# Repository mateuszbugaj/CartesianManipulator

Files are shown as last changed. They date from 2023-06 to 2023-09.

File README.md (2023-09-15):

# CartesianManipulator
This repository contains the firmware for a three-axis manipulator system. The manipulator utilizes three stepper motors controlled by A4988 stepper motor drivers. This project is designed for AVR microcontrollers.

## Overview
The manipulator has three axes: X, Y, and Z, each controlled by a stepper motor. Each axis also has an edge switch to determine its limit. The project code includes routines for handling move commands, speed changes, precision and normal mode, and homing.

Demo of the manipulator: [CartesianManipulatorDemo.gif](CartesianManipulatorDemo.gif) <br/><br/>
df

The project also includes a USART serial communication module and a basic command parser for controlling the manipulator. The manipulator can be controlled in relative or absolute positioning modes.

## Hardware
The hardware requirements for this project include:

1. AVR microcontroller
2. Three A4988 stepper motor drivers
3. Three stepper motors
4. Three edge switches
5. Gripper with servo motor

Files describing PCB layout can be found in `PCB/` directory.

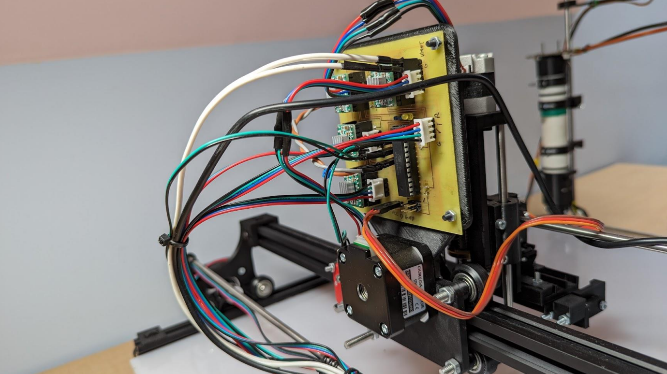
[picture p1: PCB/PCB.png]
df


## Software
The firmware is written in C and requires AVR GCC to compile.

Clone this repository to your local machine.
Open the project in your AVR development environment.
Build the project and flash the compiled firmware onto your AVR microcontroller.

```bash
make && make flash
```

## Usage
You can control the manipulator via USART using the following commands:

1. G0 \<X> \<Y> \<Z> : Move the manipulator to the specified position.
2. G28 : Home the manipulator.
3. F \<S> : Change the speed of the manipulator.
4. PREC : Switch the manipulator to precision mode.
5. NORM : Switch the manipulator to normal mode.
6. M \<G> : Control the gripper openness.
7. ZERO : Zero the manipulator's position.
8. LIMITX \<L> \<U> : Set the lower and upper limits for the X axis.
9. LIMITY \<L> \<U> : Set the lower and upper limits for the Y axis.
10. LIMITZ \<L> \<U> : Set the lower and upper limits for the Z axis.
11. G90 : Switch to relative positioning mode.
12. G91 : Switch to absolute positioning mode.

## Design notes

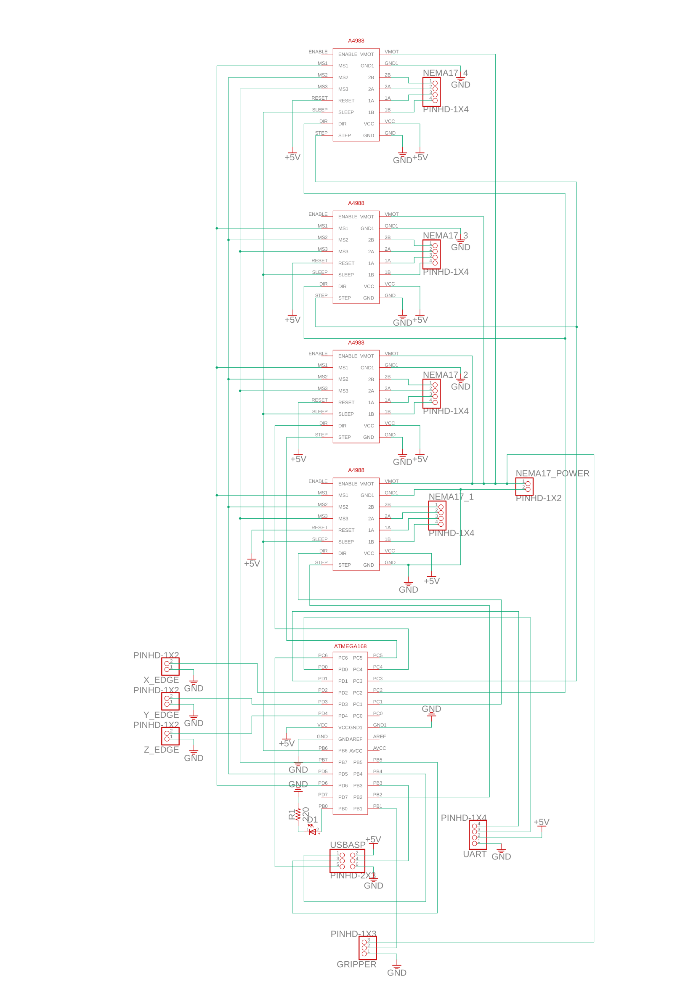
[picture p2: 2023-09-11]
PCB/PCB_Schematics.png

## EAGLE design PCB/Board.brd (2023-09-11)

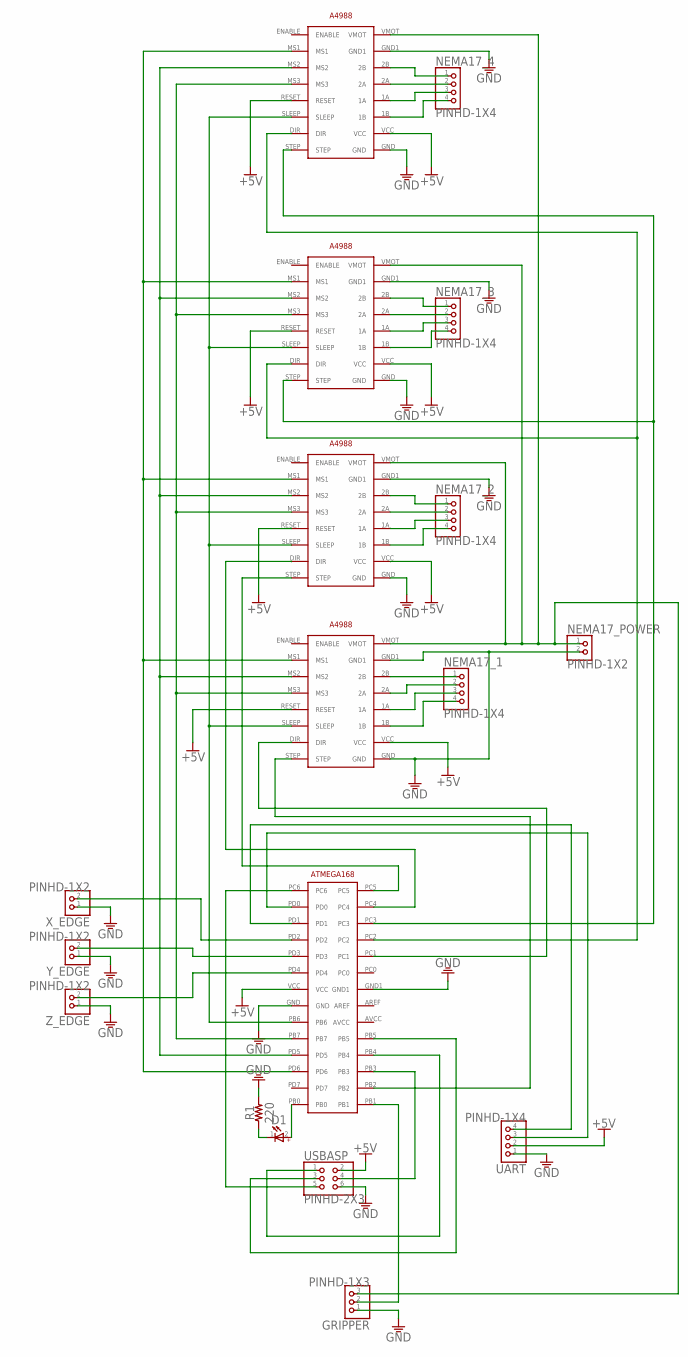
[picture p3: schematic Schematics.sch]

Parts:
D1: 151033BS03000; WL-TMRW_3MM_STOPPER
GRIPPER: PINHD-1X3; 1X03
NEMA17_1, NEMA17_2, NEMA17_3, NEMA17_4: PINHD-1X4; 1X04
NEMA17_POWER: PINHD-1X2; 1X02
R1: 220; RESAD724W46L381D178B
U$1: ATMEGA168; ATMEGA168FOOTPRINT
U$2, U$3, U$4, U$5: A4988; A498-FOOTPRINT
UART: PINHD-1X4; 1X04
USBASP: PINHD-2X3; 2X03
X_EDGE: PINHD-1X2; 1X02
Y_EDGE: PINHD-1X2; 1X02
Z_EDGE: PINHD-1X2; 1X02

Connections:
+5V: U$1.VCC, U$2.RESET, U$2.VCC, U$3.RESET, U$3.VCC, U$4.RESET, U$4.VCC, U$5.RESET, U$5.VCC, UART.2, USBASP.2
GND: GRIPPER.1, NEMA17_POWER.2, R1.2, U$1.GND, U$1.GND1, U$2.GND, U$2.GND1, U$3.GND, U$3.GND1, U$4.GND, U$4.GND1, U$5.GND, U$5.GND1, UART.1, USBASP.6, X_EDGE.1, Y_EDGE.1, Z_EDGE.1
unnamed: U$1.PB3, USBASP.4
unnamed: U$1.PB4, USBASP.1
unnamed: U$1.PB5, USBASP.3
unnamed: U$1.PC6, USBASP.5
unnamed: D1.2 (+), U$1.PB0
unnamed: D1.1 (-), R1.1
unnamed: U$1.PD0, UART.3
unnamed: U$1.PD1, UART.4
unnamed: NEMA17_1.1, U$2.2B
unnamed: NEMA17_1.2, U$2.2A
unnamed: NEMA17_1.3, U$2.1A
unnamed: NEMA17_1.4, U$2.1B
unnamed: U$1.PB2, U$2.STEP
unnamed: GRIPPER.3, NEMA17_POWER.1, U$2.VMOT, U$3.VMOT, U$4.VMOT, U$5.VMOT
unnamed: U$1.PC1, U$2.DIR
unnamed: U$1.PB6, U$2.SLEEP, U$3.SLEEP, U$4.SLEEP, U$5.SLEEP
unnamed: U$1.PB7, U$2.MS3, U$3.MS3, U$4.MS3, U$5.MS3
unnamed: U$1.PD5, U$2.MS2, U$3.MS2, U$4.MS2, U$5.MS2
unnamed: U$1.PD6, U$2.MS1, U$3.MS1, U$4.MS1, U$5.MS1
unnamed: NEMA17_2.4, U$3.1B
unnamed: NEMA17_2.3, U$3.1A
unnamed: NEMA17_2.2, U$3.2A
unnamed: NEMA17_2.1, U$3.2B
unnamed: U$1.PC5, U$3.STEP
unnamed: U$1.PC4, U$3.DIR
unnamed: NEMA17_3.4, U$4.1B
unnamed: NEMA17_3.3, U$4.1A
unnamed: NEMA17_3.2, U$4.2A
unnamed: NEMA17_3.1, U$4.2B
unnamed: U$1.PC3, U$4.STEP, U$5.STEP
unnamed: U$1.PC2, U$4.DIR, U$5.DIR
unnamed: NEMA17_4.4, U$5.1B
unnamed: NEMA17_4.3, U$5.1A
unnamed: NEMA17_4.2, U$5.2A
unnamed: NEMA17_4.1, U$5.2B
unnamed: U$1.PD2, X_EDGE.2
unnamed: U$1.PD3, Y_EDGE.2
unnamed: U$1.PD4, Z_EDGE.2
unnamed: GRIPPER.2, U$1.PB1

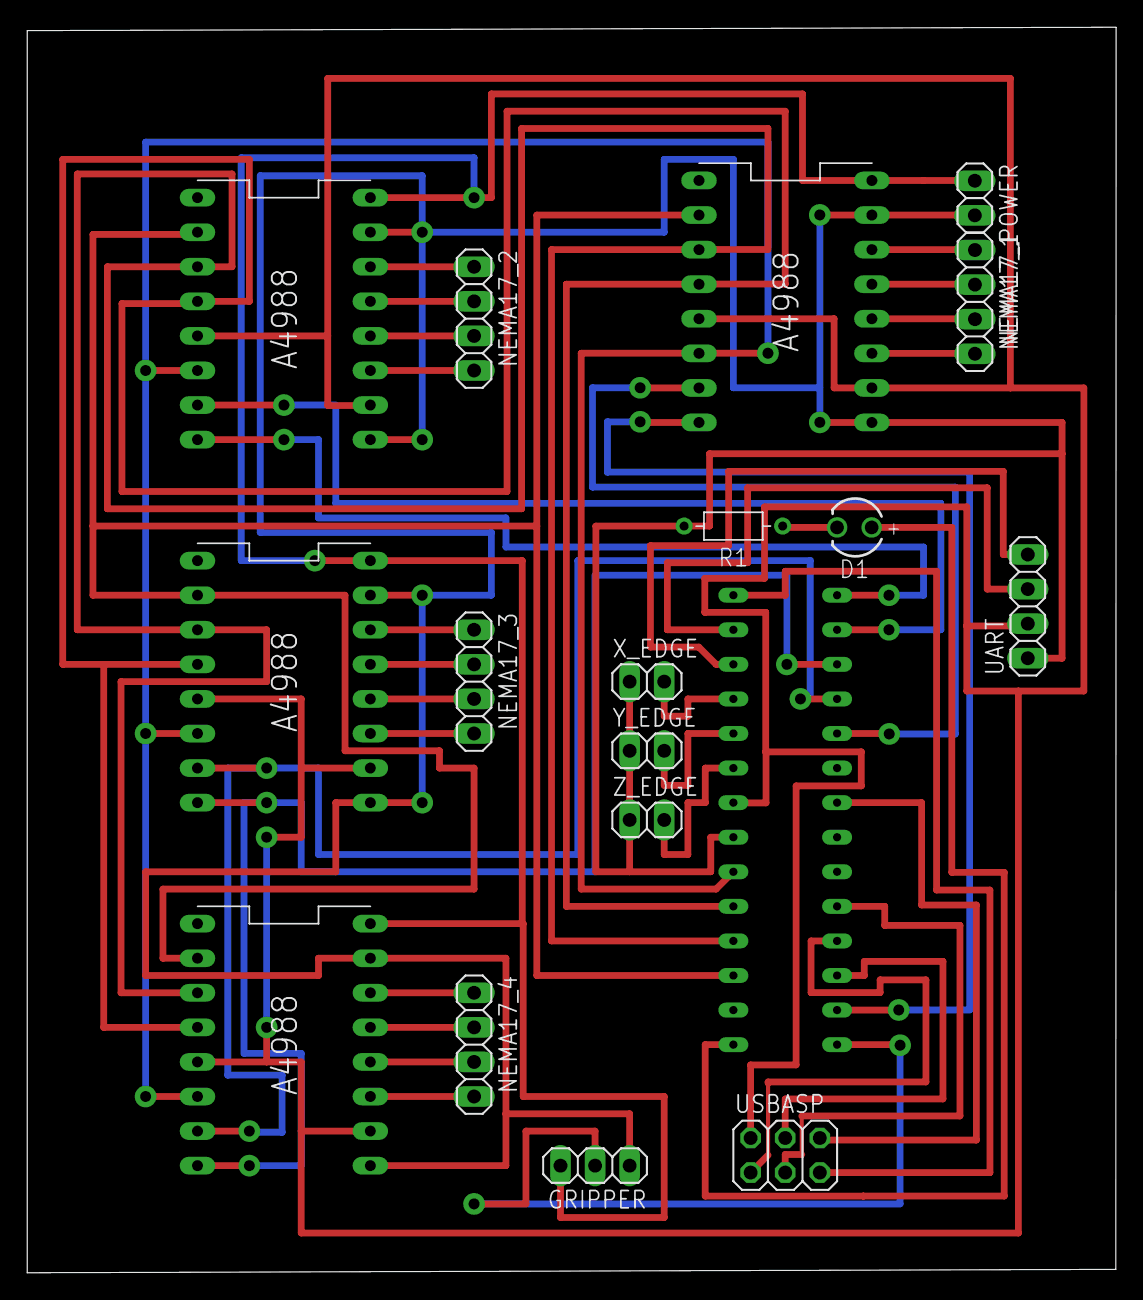
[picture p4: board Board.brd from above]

Board: 2 copper layers, 80.0 x 91.5 mm, 18 parts (0 on the bottom side), 41 nets.

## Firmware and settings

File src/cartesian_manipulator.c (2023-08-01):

#include <avr/io.h>
#include <util/delay.h>
#include <avr/power.h>

#include "a4988.h"
#include "usart.h"
#include "parser.h"
#include "gripper.h"

#define PRECISION_SPEED 2
#define NORMAL_SPEED 100

typedef struct {
    char direction;
    A4988* motor;
    GPIOPin* edgeSwitch;
    uint8_t state;
    uint8_t oldState;
    bool edgeDetected;
    bool edgeRead;
	uint8_t homing; // A 3 step process of homing
    int16_t zero_after_homing; // distance in mm to move after homing
    float pos;
    float limit_low;
    float limit_up;
    float mm_per_revolution;
} Axis;

A4988 motor_x = {
    .step = { .port = &PORTC, .pin = PC1 },
    .dir = { .port = &PORTB, .pin = PB2 },
    .sleep = { .port = &PORTB, .pin = PB6},
    .ms1 = { .port = &PORTD, .pin = PD6},
    .ms2 = { .port = &PORTD, .pin = PD5},
    .ms3 = { .port = &PORTB, .pin = PB7}
};

A4988 motor_y = {
    .step = { .port = &PORTC, .pin = PC2 },
    .dir = { .port = &PORTC, .pin = PC3 },
    .sleep = { .port = &PORTB, .pin = PB6},
    .ms1 = { .port = &PORTD, .pin = PD6},
    .ms2 = { .port = &PORTD, .pin = PD5},
    .ms3 = { .port = &PORTB, .pin = PB7}
};

A4988 motor_z = {
    .step = { .port = &PORTC, .pin = PC4 },
    .dir = { .port = &PORTC, .pin = PC5 },
    .sleep = { .port = &PORTB, .pin = PB6},
    .ms1 = { .port = &PORTD, .pin = PD6},
    .ms2 = { .port = &PORTD, .pin = PD5},
    .ms3 = { .port = &PORTB, .pin = PB7}
};

GPIOPin edge_switch_x = { .port = &PORTD, .pin = PD2 };
GPIOPin edge_switch_y = { .port = &PORTD, .pin = PD3 };
GPIOPin edge_switch_z = { .port = &PORTD, .pin = PD4 };

Axis axis_x = { 
    .direction = 'x',
	.motor = &motor_x, 
	.edgeSwitch = &edge_switch_x,
	.edgeDetected = false };

Axis axis_y = { 
    .direction = 'y',
	.motor = &motor_y, 
	.edgeSwitch = &edge_switch_y,
	.edgeDetected = false };

Axis axis_z = { 
    .direction = 'z',
	.motor = &motor_z, 
	.edgeSwitch = &edge_switch_z,
	.edgeDetected = false };

bool homing = false;
bool moving = false;
bool relative_positioning = true;
int32_t tempSpeed = 0;

bool checkLimits(Axis* axis, float mm){
    float newPos;

    if(relative_positioning == true){
        newPos = axis->pos + mm;
    } else {
        newPos = mm;
        mm = newPos - axis->pos;
    }

    if(newPos < axis->limit_low || newPos > axis->limit_up){
        usart_print_char(axis->direction);
        usart_print(" above limit\n\r");

        return false;
    }

    return true;
}

void move(Axis* axis, float mm) {
    float newPos;

    if(relative_positioning == true){
        newPos = axis->pos + mm;
    } else {
        newPos = mm;
        mm = newPos - axis->pos;
    }

    axis->pos = newPos;

    usart_print_char(axis->direction);
    usart_print(" new position: ");
    usart_print_num(newPos);
    usart_print("\n\r");

    float full_steps_per_revolution = 200.0f;
    float steps_per_mm = full_steps_per_revolution / axis->mm_per_revolution;
    float steps = mm * steps_per_mm;
    int16_t full_steps = (int16_t) steps;

    a4988_move_steps(axis->motor, full_steps);
}

void handle_move_command(float parameters[], uint8_t param_count) {
    if(param_count != 3) return;

    if(checkLimits(&axis_x, parameters[0]) && checkLimits(&axis_x, parameters[0]) && checkLimits(&axis_x, parameters[0])) {
        move(&axis_x, parameters[0]);
        move(&axis_y, parameters[1]);
        move(&axis_z, parameters[2]);

        moving = true;
    } else {
        usart_print("OK\n\r");
    }
}

void debounce_and_check_edge_switch(Axis* axis) {
    bool current_state = gpio_pin_read(*(axis->edgeSwitch)) == LOW;
    if (current_state && axis->oldState != current_state) {
        axis->edgeDetected = true;
        axis->edgeRead = false;
    } else if (!current_state && axis->oldState != current_state) {
        axis->edgeDetected = false;
    }
    axis->oldState = current_state;
}

void home_axis(Axis* axis){
	axis->homing = 1;
    relative_positioning = true;
}

void home_axis_pooling(Axis* axis){
    debounce_and_check_edge_switch(axis);

    if(axis->homing == 1){
        if(!axis->motor->moving){
            a4988_move_steps(axis->motor, 20);
        }
    }

    if (axis->homing && axis->edgeDetected && !axis->edgeRead) {
        axis->homing = 2;
        a4988_move_steps(axis->motor, -50);
        axis->edgeRead = true;
    }

    if(axis-> homing == 2 && !axis->motor->moving){
        move(axis, - axis->zero_after_homing);
        axis->homing = 0;
    }
}

void handle_home_command(float parameters[], uint8_t param_count){
    home_axis(&axis_x);
    home_axis(&axis_y);
    home_axis(&axis_z);
    homing = true;
}

void handle_change_speed_command(float parameters[], uint8_t param_count){
    a4988_set_speed(axis_x.motor, parameters[0]);
    a4988_set_speed(axis_y.motor, parameters[0]);
    a4988_set_speed(axis_z.motor, parameters[0] * 4);

    usart_print("OK\n\r");
}

void handle_precision_mode_command(float parameters[], uint8_t param_count){
    a4988_set_speed(axis_x.motor, PRECISION_SPEED);
    a4988_set_speed(axis_y.motor, PRECISION_SPEED);
    a4988_set_speed(axis_z.motor, PRECISION_SPEED * 4);
    a4988_set_microstepping(&motor_x, 8);
    a4988_set_microstepping(&motor_y, 8);
    a4988_set_microstepping(&motor_z, 8);

    usart_print("OK\n\r");
}

void handle_normal_mode_command(float parameters[], uint8_t param_count){
    a4988_set_speed(axis_x.motor, NORMAL_SPEED);
    a4988_set_speed(axis_y.motor, NORMAL_SPEED);
    a4988_set_speed(axis_z.motor, NORMAL_SPEED * 4);
    a4988_set_microstepping(&motor_x, 4);
    a4988_set_microstepping(&motor_y, 4);
    a4988_set_microstepping(&motor_y, 4);

    usart_print("OK\n\r");
}

void handle_gripper_command(float parameters[], uint8_t param_count){
    if(param_count == 1){
        uint8_t opennsess = (uint8_t) parameters[0];
        gripper_set_openness(opennsess);
    }

    usart_print("OK\n\r");
}

void handle_zero_command(float parameters[], uint8_t param_count){
    axis_x.pos = 0;
    axis_y.pos = 0;
    axis_z.pos = 0;

    usart_print("New Position: [0 0 0]\n\r");
    usart_print("OK\n\r");
}

void handle_new_limit_x_command(float parameters[], uint8_t param_count){
    if(param_count == 1){
        axis_x.limit_low = -parameters[0];
        axis_x.limit_up = parameters[0];
    } else if(param_count == 2){
        if(parameters[0] < parameters[1]){
            axis_x.limit_low = parameters[0];
            axis_x.limit_up = parameters[1];
        }
    }

    usart_print("New limits for x: [");
    usart_print_num(axis_x.limit_low);
    usart_print(", ");
    usart_print_num(axis_x.limit_up);
    usart_print("]\n\r");

    usart_print("OK\n\r");
}

void handle_new_limit_y_command(float parameters[], uint8_t param_count){
    if(param_count == 1){
        axis_y.limit_low = -parameters[0];
        axis_y.limit_up = parameters[0];
    } else if(param_count == 2){
        if(parameters[0] < parameters[1]){
            axis_y.limit_low = parameters[0];
            axis_y.limit_up = parameters[1];
        }
    }

    usart_print("New limits for y: [");
    usart_print_num(axis_y.limit_low);
    usart_print(", ");
    usart_print_num(axis_y.limit_up);
    usart_print("]\n\r");

    usart_print("OK\n\r");
}

void handle_new_limit_z_command(float parameters[], uint8_t param_count){
    if(param_count == 1){
        axis_z.limit_low = -parameters[0];
        axis_z.limit_up = parameters[0];
    } else if(param_count == 2){
        if(parameters[0] < parameters[1]){
            axis_z.limit_low = parameters[0];
            axis_z.limit_up = parameters[1];
        }
    }

    usart_print("New limits for z: [");
    usart_print_num(axis_z.limit_low);
    usart_print(", ");
    usart_print_num(axis_z.limit_up);
    usart_print("]\n\r");

    usart_print("OK\n\r");
}

void handle_positioning_mode_relative_command(float parameters[], uint8_t param_count){
    relative_positioning = true;
    usart_print("Relative positioning\n\r");
    usart_print("OK\n\r");
}

void handle_positioning_mode_absolute_command(float parameters[], uint8_t param_count){
    relative_positioning = false;
    usart_print("Relative positioning\n\r");
    usart_print("OK\n\r");
}

parser_command_handler_t command_handlers[] = {
    { .command = "G0", .callback = handle_move_command},
    { .command = "G28", .callback = handle_home_command},
    { .command = "F", .callback = handle_change_speed_command},
    { .command = "PREC", .callback = handle_precision_mode_command},
    { .command = "NORM", .callback = handle_normal_mode_command},
    { .command = "M", .callback = handle_gripper_command},
    { .command = "ZERO", .callback = handle_zero_command},
    { .command = "LIMITX", .callback = handle_new_limit_x_command},
    { .command = "LIMITY", .callback = handle_new_limit_y_command},
    { .command = "LIMITZ", .callback = handle_new_limit_z_command},
    { .command = "G90", .callback = handle_positioning_mode_relative_command},
    { .command = "G91", .callback = handle_positioning_mode_absolute_command}
};

int main() {
	clock_prescale_set(clock_div_1);

	// Initialize USART
    usart_init();
    parser_init(command_handlers, sizeof(command_handlers)/sizeof(command_handlers[0]));

    // Initialize A4988 drivers
	uint8_t microstepping = 4;
    a4988_init(&motor_x);
    a4988_set_microstepping(&motor_x, microstepping);
    a4988_set_speed(&motor_x, 100);
    axis_x.zero_after_homing = 170;
    axis_x.limit_low = -100;
    axis_x.limit_up = 100;
    axis_x.mm_per_revolution = 40.0f; // for motors connected to the tooth belt

    a4988_init(&motor_y);
    a4988_set_microstepping(&motor_y, microstepping);
    a4988_set_speed(&motor_y, 100);
    axis_y.zero_after_homing = 100;
    axis_y.limit_low = -100;
    axis_y.limit_up = 100;
    axis_y.mm_per_revolution = 40.0f; // for motors connected to the tooth belt

    a4988_init(&motor_z);
    a4988_set_microstepping(&motor_z, microstepping);
    a4988_set_speed(&motor_z, 400);
    axis_z.zero_after_homing = 40;
    axis_z.limit_low = -50;
    axis_z.limit_up = 50;
    axis_z.mm_per_revolution = 2.0f; // for motors connected to a T2 screw

 	// Initialize the edge switches
    gpio_pin_direction(edge_switch_x, INPUT);
    gpio_pin_direction(edge_switch_y, INPUT);
    gpio_pin_direction(edge_switch_z, INPUT);

    gpio_pin_write(edge_switch_x, HIGH);
    gpio_pin_write(edge_switch_y, HIGH);
    gpio_pin_write(edge_switch_z, HIGH);

    // Initialize gripper
    gripper_init();

	GPIOPin LED = { .port = &PORTB, .pin = PB0 };
	gpio_pin_direction(LED, OUTPUT);

    usart_print("Cartesian Manipulator start...\n\r");
    while (1) {
        home_axis_pooling(&axis_x);
        home_axis_pooling(&axis_y);
        home_axis_pooling(&axis_z);

        // Confirm that homing has ended
        if(homing == true && 
        axis_x.homing == false && 
        axis_y.homing == false && 
        axis_z.homing == false && 
        axis_x.motor->moving == false && 
        axis_y.motor->moving == false && 
        axis_z.motor->moving == false){
            homing = false;
            axis_x.pos = 0;
            axis_y.pos = 0;
            axis_z.pos = 0;

            usart_print("OK\n\r");
        }

        // Confirm that movement has ended
        if(moving == true && axis_x.motor->moving == false && axis_y.motor->moving == false && axis_z.motor->moving == false){
            moving = false;

            usart_print("OK\n\r");
        }

        if(a4988_is_moving(&motor_x) || a4988_is_moving(&motor_y) || a4988_is_moving(&motor_z)){
			gpio_pin_write(LED, HIGH);
			gpio_pin_write(motor_x.sleep, HIGH);
        } else {
			gpio_pin_write(LED, LOW);
			gpio_pin_write(motor_x.sleep, LOW);
		}
    }

    return 0;
}

ISR(TIMER0_COMPA_vect) {
    a4988_step(&motor_x);
    a4988_step(&motor_y);
    a4988_step(&motor_z);
}

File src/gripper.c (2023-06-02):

#include "gripper.h"

int pulse;
int multiplier;
int openness; // percenage of how much the gripper is open (0 to 100).
int servo_timer_counter;

/* 
    Set up 16-bit Timer1 to give a modulated pulse every 20ms on PB1.

    TCCR1A
        Set waveform generation mode to 'Fast PWM'
        Set output of PWM on OC1A (PB1)
    TCCR1B
        Set waveform generation mode to 'Fast PWM'
        /8 prescaler so one ms. is 1000 cycles at 8 MHz clock
    ICR1
        Set top value of the couner (20000 for 20 ms.)
*/
void gripper_init_timer(void) {
    TCCR1A |= (1 << WGM11) | (1 << COM1A1);
    TCCR1B |= (1 << WGM12) | (1 << WGM13);
    TCCR1B |= (1 << CS11);
    ICR1 = 20000;
    
    DDRB |= (1 << PB1);
    OCR1A = pulse;

    sei();
}

void gripper_init(void){
    pulse = PULSE_MIN;
    multiplier = 1;
    openness = 50;
    servo_timer_counter = 0;

    gripper_init_timer();
}

void gripper_set_openness(int new_openness){
    openness = new_openness;

    pulse = (openness - 0.0) / (100.0 - 0.0) * (PULSE_MIN - PULSE_MAX) + PULSE_MAX;
    OCR1A = pulse;
}

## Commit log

2023-05-26 Updated StepperMotorDriver library submodule
2023-05-27 Added X and Y axis moving, modified parser to handle commands with multiple float params
2023-05-28 Initial homing command
2023-05-31 Clearing parser context after command, working homing, removed acceleration (we will get them next time)
2023-06-02 Added gripper support
2023-06-03 Added Z axis
2023-06-03 Fixed homing
2023-06-12 Added command to set the z axis limit
2023-07-27 Fixed Z axis movement confirmation, no axis moves if one is out of bounds, NORMAL_SPEED adjusted
    [cartesian_manipulator.c]
2023-08-01 Added Z axis speed adjustment
2023-09-11 PCB and README
    [Board.brd, Schematics.sch]

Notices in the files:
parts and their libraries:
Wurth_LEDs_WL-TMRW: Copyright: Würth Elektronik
